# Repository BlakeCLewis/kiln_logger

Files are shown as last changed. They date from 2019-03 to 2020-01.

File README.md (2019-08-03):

# kiln_logger

Heat is dangerous! Evaluate the risk and make your go/no-go decision!

I have had issues with the thermocouple chip getting too hot when air temp is above 90F. It is in a metal box, 2' away from the kiln. Last firning, when the kiln was within 30C of cone 6, it started under reading. I added a computer muffin fan to cool the electronics.

Parts and pieces: I think it adds up to ~ $70 and some shipping.

- Raspberry pi: any of these will work, $10 Zero W is cheapest, but a Pi 3b runs much faster and will give a desktop.

		https://www.adafruit.com/product/3775

		https://www.adafruit.com/product/3055

		https://www.adafruit.com/product/4027

		https://www.adafruit.com/product/3400

- 5V power supply: for the Pi

		https://www.adafruit.com/product/1995

- MicroSD card: you will also need a way to write the image, e.g. usb adapter

		https://www.amazon.com/SanDisk-microSDHC-Standard-Packaging-SDSQUNC-032G-GN6MA/dp/B010Q57T02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

- MAX31856 thermocouple module:

		https://www.adafruit.com/product/3263

- Female <=> Female jumper wires:

		https://www.adafruit.com/product/266

- 20x4 LCD w/ i2c backpack: it will print to console too.

		https://www.amazon.com/gp/product/B01GPUMP9C/ref=oh_aui_detailpage_o01_s00?ie=UTF8&psc=1
		or
		https://www.adafruit.com/product/198
		https://www.adafruit.com/product/292

- High temperature (2372 F) type K thermocouple:

		https://www.amazon.com/Temperature-Thermocouple-Ceramic-connector-CR-06/dp/B0713X6XG3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

- Download Raspbien Stretch or newer and write it to the MicroSD:

		https://www.raspberrypi.org/downloads/raspbian/
		boot it up
		expand the partition, it ask on first boot
		configure network
		update software 'apt-get update' and 'apt-get upgrade'

Wiring:

- fritz: 'https://raw.githubusercontent.com/BlakeCLewis/kiln_logger/master/logger_bb.png'

- Pin-Out:

		Device	PI
		----------	-------
		RPLCD VCC:	5V
		RPLCD GND:	GND
		RPLCD SDA:	GPIO 2
		RPLCD SCL:	GPIO 3

		MAX31856 3vo:	3.3v
		MAX31856 GND:	GND
		MAX31856 SDO:	GPIO 9
		MAX31856 SDI:	GPIO 10
		MAX31856 CS:	GPIO 8
		MAX31856 SCK:	GPIO 11

- Install project files:

		git clone git@github.com:BlakeCLewis/kiln_logger.git

- Install sqlite3:

		sudo apt-get install sqlite3

- Configure raspberry pi interfaces:

		sudo raspi-config
		#enable interfaces ssh, ic2 & spi

- Instal RPLCD for the 20x4 lcd:

		sudo pip3 install RPLCD

- Install MAX31856 Module:

		cd
		sudo apt-get update
		sudo apt-get install build-essential python3-pip python3-dev python3-smbus git
		git clone https://github.com/adafruit/Adafruit_Python_GPIO.git
		cd Adafruit_Python_GPIO
		sudo python3 setup.py install
		cd
		git clone git@github.com:johnrbnsn/Adafruit_Python_MAX31856.git
		cd Adafruit_Python_MAX31856
		sudo python3 setup.py install

- test modules:

		cd ~/kiln_logger
		python3 display.py
		python3 max31856_test.py

- create the database:

		sqlite3 ~/kiln_logger.sqlite3
		CREATE TABLE firelog(RunID number, datime datetime, t number);
		.schema
		.exit

- run the logger

		cd ~/kiln_logger
		./logger.py -i <intger Run_ID> -s <interval in seconds>

- access data:

		ssh pi@<pi ipaddres>
		sqlite3 kilnlog.sqlite3
		select * from firelog where runid=420 order by datime asc;

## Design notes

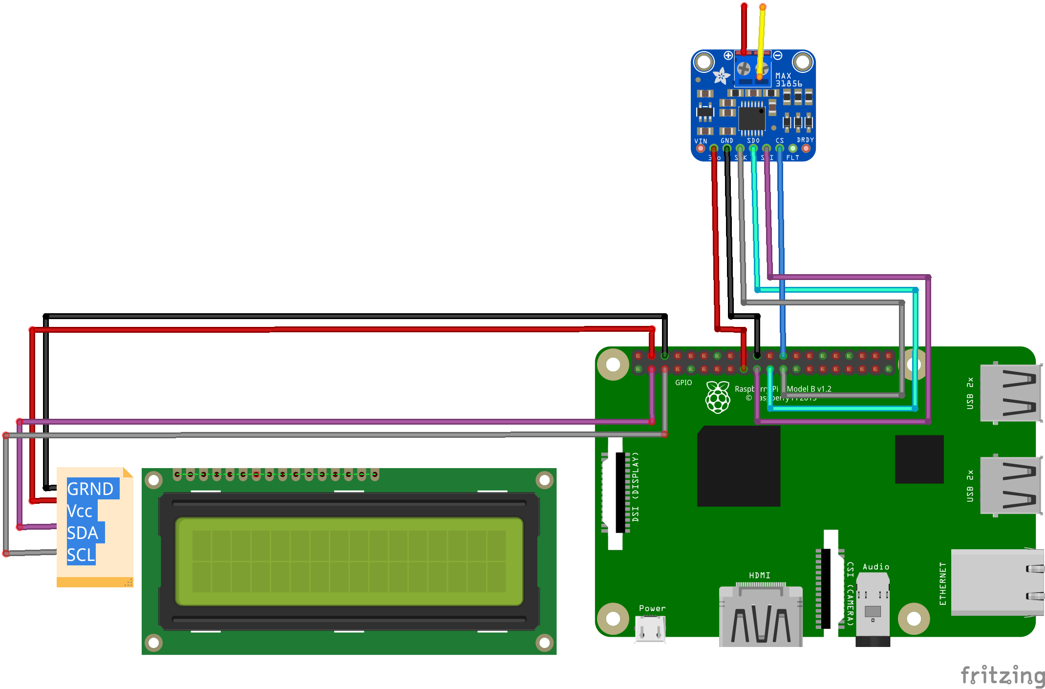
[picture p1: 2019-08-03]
logger_bb.png

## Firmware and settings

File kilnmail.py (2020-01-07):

# set:
#     recipient to you phone email address
#     gmail_sender to your gmail account (I set up a new account specifically for this purpose)
#     gmail_passwd
#     gmail account settings set "Less secure app access" to "on"

def send_email(subject,text):

    #your phone
    recipient = 'XXXXXXXXXXX@msg.fi.google.com'
    # Gmail Sign In
    gmail_sender = 'XXXXXXXXXX@gmail.com'
    gmail_passwd = 'XXXXXXXXXXX'

    server = smtplib.SMTP('smtp.gmail.com', 587)
    server.ehlo()
    server.starttls()
    server.login(gmail_sender, gmail_passwd)
    msg = '\r\n'.join(['To: %s' % recipient, 'From: %s' % gmail_sender,'Subject: %s' % subject,'', text])

    try:
        server.sendmail(gmail_sender, recipient, msg)
        print ('email sent')
    except:
        print ('error sending mail')
        server.quit()

#object
class kiln_state(itp,otp):
#  track: 20 temp/timestamp/trend
#  event: STATE change|PEAK|+100C 
#       'PEAK'  if high is > 10 minutes old and trend < -15
#  state: CLIMB|HOLD|FALL
#       'HOLD'  if abs(trend) < 4
#       'CLIMB' if trend is > 6
#       'FALL'  if  trend is < -6

    def __init__(self):
        datime = time.time()
        tp = itp
        length = 20
        self.ti = deque(maxlen=length) #time
        self.ti.appendleft(datime)
        self.tp = deque(maxlen=length) #temp
        self.tp.appendleft(itp)
        self.td = deque(maxlen=length) #trend
        self.td.appendleft(0)
        self.state = 'HOLD'
        self.high = temp
        self.peak = 0
        self.peaked = False

        
    def _trending(self):
        return self.td.count(1) + self.td.count(-1)

    def _rate(self): #need to turn this into C/hour
        return (self.tp(0) - self.tp(-1)) / (self.ti(0)-self.ti(-1))

    def update(self,itp,otp):
        itp = round(itp)
        otp = round(otp)
        ti = time.time

        ddiiqq = itp - self.ti(0)
        if ddiiqq = 0:
            trend = 0
        elif ddiiqq < 0:
            trend = -1
        else:
            trend = 1
        self.tp.appendleft(itp)
        self.ti.appendleft(ti)
        self.td.appendleft(trend)

        if self.state == 'CLIMB':
            if self.high < itp:
                self.high = itp
                self.hightime = time.time
            trend = _trending()
            if abs(trend) < 4 and (self.tp(0)-self.tp(-1)) < 0 :
                self.state = 'HOLD'
                #notify
            elif (trend < -4) and (self.tp(0) - self.tp(-1) < 0):
                self.state = 'FALL'
                #notify
            
        elif self.state == 'HOLD'
            if (trending() > 4) and (self.tp(0) - self.tp(-1) > 0):
                self.state = 'CLIMB'
                #notify
            elif (trending() < -4) and (self.tp(0) - self.tp(-1) < 0)::
                self.state = 'FALL'
                #notify

        elif self.state == 'FALL'
            #need to turn this into minutes
            if 8 < (self.hightime - self.ti(0)) 
                    and (trending() < -10 
                    and ((!self.peaked) or (self.peak<self.high)):
                self.peak = self.high
                self.peaktime = self.hightime
                #report peak temp ?C @ timestamp
            if :
                self.state = 'CLIMB'
            elif :
                self.state = 'HOLD'


if __name__=='__main__':
    import smtplib
    import time
    from collections import deque
    #test msg
    send_email('rpi.kiln allgood','this is not the kiln you are looking for')
-

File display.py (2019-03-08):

"""
this class is used in main program pilnfired.py
it can be run standalone 'python3 display.py' to test display w/ mock data 
"""

import sys
import RPi.GPIO as GPIO
import spidev
from RPLCD.i2c import CharLCD
from itertools import cycle

class display(CharLCD):
    def __init__(self):
        CharLCD.__init__(self,i2c_expander='PCF8574', address=0x27, port=1,
            cols=20, rows=4, dotsize=8, charmap='A02',
            auto_linebreaks=False, backlight_enabled=True
        )
        smile=(0b00000,0b01010,0b01010,0b00000,0b10001,0b10001,0b01110,0b00000)
        degre=(0b01100,0b10010,0b10010,0b01100,0b00000,0b00000,0b00000,0b00000)
        bksls=(0b00000,0b10000,0b01000,0b00100,0b00010,0b00001,0b00000,0b00000)
        self.create_char(0, smile) #\x00
        self.create_char(1, degre) #\x01
        self.create_char(2, bksls) #\x02
        self._wheeley = '-','\x02','|','/','\x00'
        self._wheel = cycle(self._wheeley)
        self.blank20 = '                    '

    def writeFire(self,State,ID,Seg,ReadT,TargT,RampT,ETR):

        line0 = str(State) + '                   '

        line1a = 'Pr ' + str(ID) + '      '
        line1b = 'Sg ' + str(Seg) + ' ' + str(next(self._wheel)) + '   '
        line1 = line1a[0:11] + line1b[0:9]

        line2a = 'Tm ' + str(int(ReadT)) + '\x01C  '
        line2b = 'Rp ' + str(int(RampT)) + '\x01  '
        line2 = line2a[0:11] + line2b[0:10]

        line3a = 'Tr ' + str(int(TargT)) + '\x01C   '
        line3b = ETR
        line3 = line3a[0:11] + line3b[0:8]

        self.cursor_pos = (0, 0)
        self.write_string(line0[0:19])
        self.cursor_pos = (1, 0)
        self.write_string(line1[0:19])
        self.cursor_pos = (2, 0)
        self.write_string(line2[0:19])
        self.cursor_pos = (3, 0)
        self.write_string(line3[0:19])

    def writeIdle(self,ReadT0,ReadI0,ReadT1,ReadI1):
        line0='IDLE: ' + next(self._wheel) + '             '
        line1='T0 ' + str(int(ReadT0)) + '\x01C  ' + str(int(ReadI0)) + '\x01C     '
        line2='T1 ' + str(int(ReadT1)) + '\x01C  ' + str(int(ReadI1)) + '\x01C     '
        #line3='T2 ' + str(int(ReadT2)) + '\x01C  ' + str(int(ReadI2)) + '\x01C     '

        self.cursor_pos = (0, 0)
        self.write_string(line0[0:19])
        self.cursor_pos = (1, 0)
        self.write_string(line1[0:19])
        self.cursor_pos = (2, 0)
        self.write_string(line2[0:19])
        #self.cursor_pos = (3, 0)
        #self.write_string(line3[0:19])

    def writeLog(self,RunID,dastrtime,temp0,temp1,temp2):
        line0='ID:' + str(RunID) + '  ' + dastrtime
        line1='Tnow ' + str(round(temp0,1)) + '\x01C     '
        line2='Tn-1 ' + str(round(temp1,1)) + '\x01C     '
        line3='Tn-2 ' + str(round(temp2,1)) + '\x01C     '

        self.cursor_pos = (0, 0)
        self.write_string(line0[0:19])
        self.cursor_pos = (1, 0)
        self.write_string(line1[0:19])
        self.cursor_pos = (2, 0)
        self.write_string(line2[0:19])
        self.cursor_pos = (3, 0)
        self.write_string(line3[0:19])


if __name__=='__main__':
    from signal import *
    import os
    import RPi.GPIO as GPIO
    from time import sleep
    #from display import display
    duh=display()

    def clean(*args):
        print('doing the cleanup')
        duh.close(clear=True)
        os._exit(0)
    for sig in (SIGABRT, SIGINT, SIGTERM):
        signal(sig, clean)

    for i in range(8):
        duh.writeFire('Running',19,2,556+i*4,1315,108,'10:00:10')
        print ('')
        sleep(3)

    for i in range(8):
        duh.writeIdle(1222+i*2,20,1225+1*2,20)
        print ('')
        sleep(3)

    duh.close(clear=True)

    clean()
